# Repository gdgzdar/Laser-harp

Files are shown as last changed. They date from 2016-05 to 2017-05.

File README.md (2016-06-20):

# Laser harp
##Project in progress...

#contact:
- j.cerny.zdar@gmail.com            - organizator
- gdgzdarnadsazavou@gmail.com       - company

##Hardware:
Sensor in frame is 100% completed

Lasers in frame is 100% completed

Arduino LCD display is 1% completed

Ardduino pragraming is 30% completed

##Sofware:
Play sound functions are completed

Play sound async is  completed

Program GUI is 50% completed

Sound Librery now has 8 instruments

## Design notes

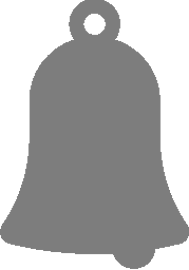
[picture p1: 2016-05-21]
app/images/instruments/iron.png

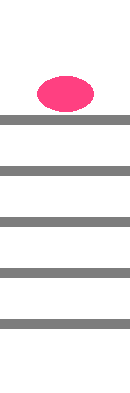
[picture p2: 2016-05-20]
app/images/notes/first-overspace-bass.png

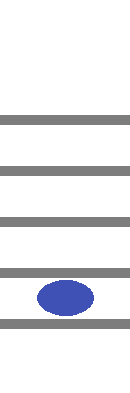
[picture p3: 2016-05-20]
app/images/notes/first-space.png

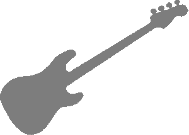
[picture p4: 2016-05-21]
app/images/instruments/bass.png

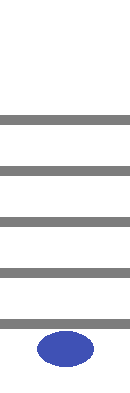
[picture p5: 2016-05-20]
app/images/notes/first-subspace.png

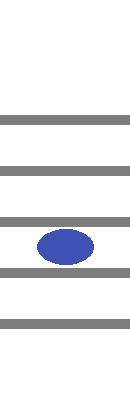
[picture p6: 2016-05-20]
app/images/notes/second-space.png

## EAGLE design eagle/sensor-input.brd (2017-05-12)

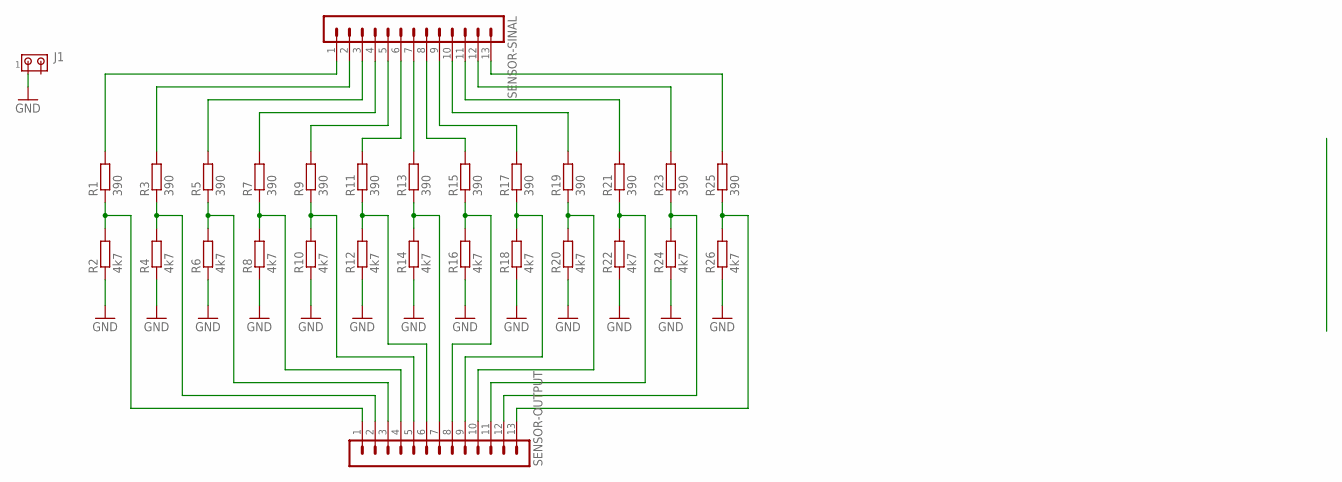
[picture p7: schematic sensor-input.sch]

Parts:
J1: MTA02-100; 10X02MTA
R1, R3, R5, R7, R9, R11, R13, R15, R17, R19, R21, R23, R25: 390; 0207/7
R2, R4, R6, R8, R10, R12, R14, R16, R18, R20, R22, R24, R26: 4k7; 0207/7
SENSOR-OUTPUT: MA13-1
SENSOR-SINAL: MA13-1

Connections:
GND: J1.1, R2.1, R4.1, R6.1, R8.1, R10.1, R12.1, R14.1, R16.1, R18.1, R20.1, R22.1, R24.1, R26.1
unnamed: R3.1, R4.2, SENSOR-OUTPUT.2
unnamed: R1.1, R2.2, SENSOR-OUTPUT.1
unnamed: R5.1, R6.2, SENSOR-OUTPUT.3
unnamed: R7.1, R8.2, SENSOR-OUTPUT.4
unnamed: R9.1, R10.2, SENSOR-OUTPUT.5
unnamed: R11.1, R12.2, SENSOR-OUTPUT.6
unnamed: R13.1, R14.2, SENSOR-OUTPUT.7
unnamed: R15.1, R16.2, SENSOR-OUTPUT.8
unnamed: R17.1, R18.2, SENSOR-OUTPUT.9
unnamed: R19.1, R20.2, SENSOR-OUTPUT.10
unnamed: R21.1, R22.2, SENSOR-OUTPUT.11
unnamed: R23.1, R24.2, SENSOR-OUTPUT.12
unnamed: R25.1, R26.2, SENSOR-OUTPUT.13
unnamed: R1.2, SENSOR-SINAL.1
unnamed: R3.2, SENSOR-SINAL.2
unnamed: R5.2, SENSOR-SINAL.3
unnamed: R7.2, SENSOR-SINAL.4
unnamed: R9.2, SENSOR-SINAL.5
unnamed: R11.2, SENSOR-SINAL.6
unnamed: R13.2, SENSOR-SINAL.7
unnamed: R15.2, SENSOR-SINAL.8
unnamed: R17.2, SENSOR-SINAL.9
unnamed: R19.2, SENSOR-SINAL.10
unnamed: R21.2, SENSOR-SINAL.11
unnamed: R23.2, SENSOR-SINAL.12
unnamed: R25.2, SENSOR-SINAL.13

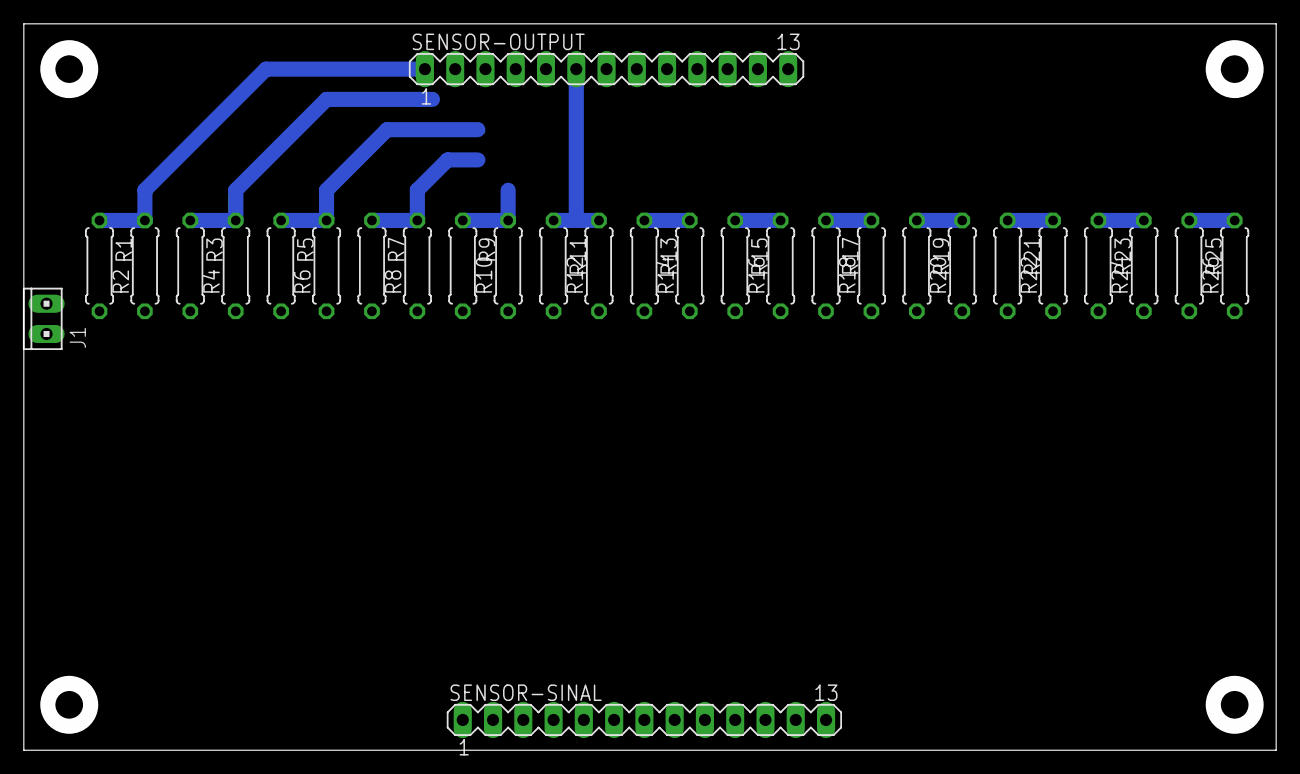
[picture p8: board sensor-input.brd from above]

Board: 2 copper layers, 105.1 x 61.0 mm, 29 parts (0 on the bottom side), 27 nets.

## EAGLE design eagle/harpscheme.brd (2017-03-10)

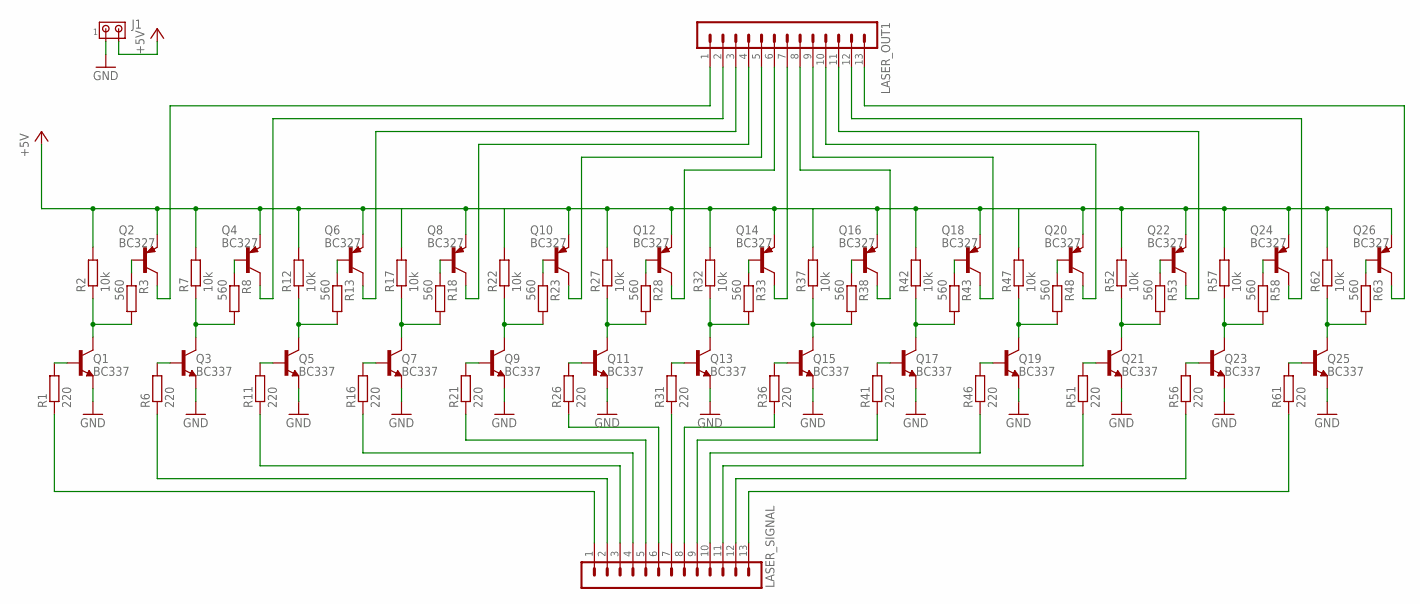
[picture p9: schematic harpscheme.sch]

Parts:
J1: MTA02-100; 10X02MTA
LASER_OUT1: MA13-1
LASER_SIGNAL: MA13-1
Q1, Q3, Q5, Q7, Q9, Q11, Q13, Q15, Q17, Q19, Q21, Q23, Q25: BC337; TO92
Q2, Q4, Q6, Q8, Q10, Q12, Q14, Q16, Q18, Q20, Q22, Q24, Q26: BC327; TO92-EBC
R1, R6, R11, R16, R21, R26, R31, R36, R41, R46, R51, R56, R61: 220; 0207/7
R2, R7, R12, R17, R22, R27, R32, R37, R42, R47, R52, R57, R62: 10k; 0207/7
R3, R8, R13, R18, R23, R28, R33, R38, R43, R48, R53, R58, R63: 560; 0207/7

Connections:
+5V: J1.2, Q2.E, Q4.E, Q6.E, Q8.E, Q10.E, Q12.E, Q14.E, Q16.E, Q18.E, Q20.E, Q22.E, Q24.E, Q26.E, R2.2, R7.2, R12.2, R17.2, R22.2, R27.2, R32.2, R37.2, R42.2, R47.2, R52.2, R57.2, R62.2
GND: J1.1, Q1.1 (E), Q3.1 (E), Q5.1 (E), Q7.1 (E), Q9.1 (E), Q11.1 (E), Q13.1 (E), Q15.1 (E), Q17.1 (E), Q19.1 (E), Q21.1 (E), Q23.1 (E), Q25.1 (E)
unnamed: Q1.2 (B), R1.2
unnamed: Q1.3 (C), R2.1, R3.2
unnamed: Q2.B, R3.1
unnamed: LASER_SIGNAL.7, R31.1
unnamed: LASER_OUT1.1, Q2.C
unnamed: Q3.2 (B), R6.2
unnamed: Q3.3 (C), R7.1, R8.2
unnamed: Q4.B, R8.1
unnamed: LASER_OUT1.2, Q4.C
unnamed: Q5.2 (B), R11.2
unnamed: Q5.3 (C), R12.1, R13.2
unnamed: Q6.B, R13.1
unnamed: LASER_SIGNAL.6, R26.1
unnamed: LASER_OUT1.3, Q6.C
unnamed: Q7.2 (B), R16.2
unnamed: Q7.3 (C), R17.1, R18.2
unnamed: Q8.B, R18.1
unnamed: LASER_SIGNAL.5, R21.1
unnamed: LASER_OUT1.4, Q8.C
unnamed: Q9.2 (B), R21.2
unnamed: Q9.3 (C), R22.1, R23.2
unnamed: Q10.B, R23.1
unnamed: LASER_SIGNAL.4, R16.1
unnamed: LASER_OUT1.5, Q10.C
unnamed: Q11.2 (B), R26.2
unnamed: Q11.3 (C), R27.1, R28.2
unnamed: Q12.B, R28.1
unnamed: LASER_SIGNAL.3, R11.1
unnamed: LASER_OUT1.6, Q12.C
unnamed: Q13.2 (B), R31.2
unnamed: Q13.3 (C), R32.1, R33.2
unnamed: Q14.B, R33.1
unnamed: LASER_SIGNAL.2, R6.1
unnamed: LASER_OUT1.7, Q14.C
unnamed: Q15.2 (B), R36.2
unnamed: Q15.3 (C), R37.1, R38.2
unnamed: Q16.B, R38.1
unnamed: LASER_SIGNAL.1, R1.1
unnamed: LASER_OUT1.8, Q16.C
unnamed: Q17.2 (B), R41.2
unnamed: Q17.3 (C), R42.1, R43.2
unnamed: Q18.B, R43.1
unnamed: LASER_SIGNAL.8, R36.1
unnamed: LASER_OUT1.9, Q18.C
unnamed: Q19.2 (B), R46.2
unnamed: Q19.3 (C), R47.1, R48.2
unnamed: Q20.B, R48.1
unnamed: LASER_SIGNAL.9, R41.1
unnamed: LASER_OUT1.10, Q20.C
unnamed: Q21.2 (B), R51.2
unnamed: Q21.3 (C), R52.1, R53.2
unnamed: Q22.B, R53.1
unnamed: LASER_SIGNAL.10, R46.1
unnamed: LASER_OUT1.11, Q22.C
unnamed: Q23.2 (B), R56.2
unnamed: Q23.3 (C), R57.1, R58.2
unnamed: Q24.B, R58.1
unnamed: LASER_SIGNAL.11, R51.1
unnamed: LASER_OUT1.12, Q24.C
unnamed: Q25.2 (B), R61.2
unnamed: Q25.3 (C), R62.1, R63.2
unnamed: Q26.B, R63.1
unnamed: LASER_SIGNAL.12, R56.1
unnamed: LASER_OUT1.13, Q26.C
unnamed: LASER_SIGNAL.13, R61.1

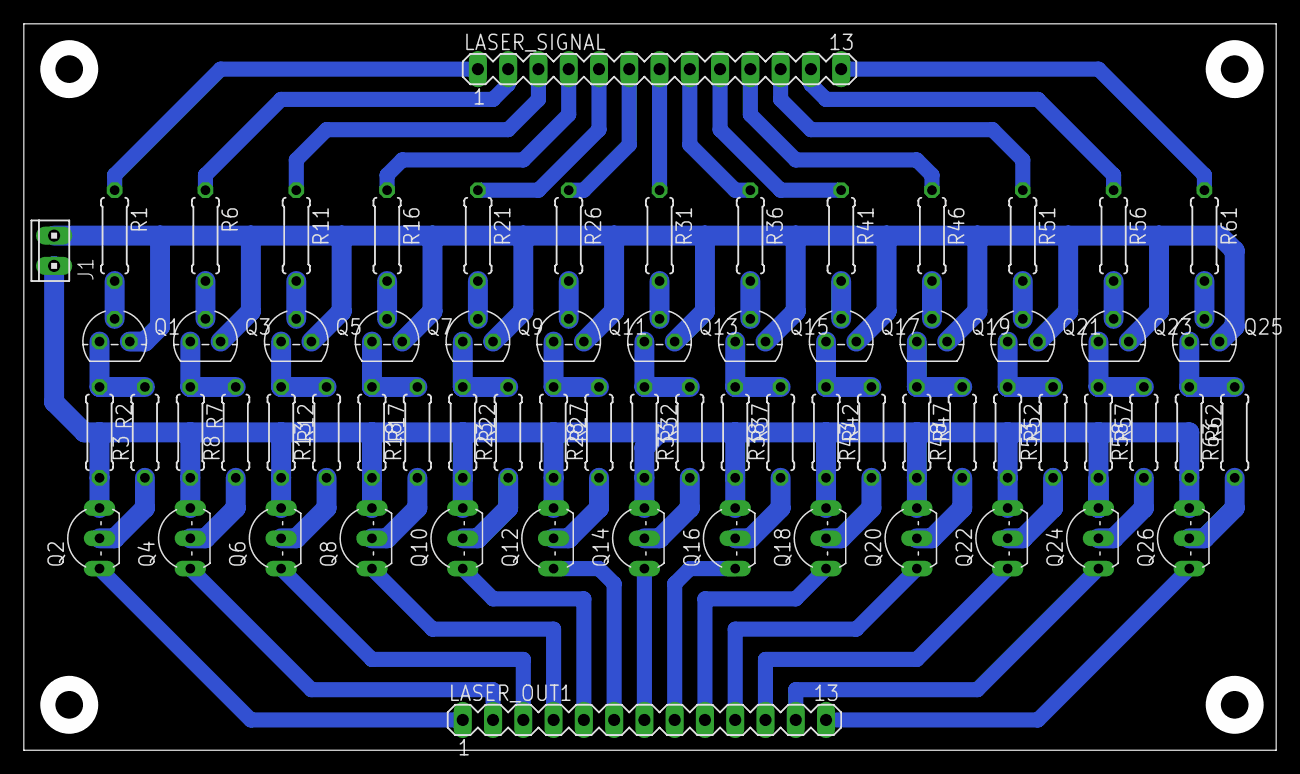
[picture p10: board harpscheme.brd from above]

Board: 2 copper layers, 105.1 x 61.0 mm, 68 parts (0 on the bottom side), 67 nets.

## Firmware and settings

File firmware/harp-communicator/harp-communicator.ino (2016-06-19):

#include "laser.cpp"
#in

static const byte NUMBER_OF_LASERS = 26;
Laser* lasers[NUMBER_OF_LASERS];

void setup() {
  Serial.begin(9600);
  for (int i = 0; i < NUMBER_OF_LASERS; i++) {
    // set pins for lasers and sensors
    int sensorPin = i + 29; // this index may be wrong
    int laserPin = i + 3; // this one too
    Serial.println(laserPin);
    pinMode(laserPin, OUTPUT);    
    pinMode(sensorPin, INPUT);
    digitalWrite(laserPin, HIGH);
    lasers[i] = new Laser(true, false, sensorPin, laserPin);
  }
}

void loop() {
  for(int i = 0; i < NUMBER_OF_LASERS; i++) {
    lasers[i]->isCrossed = digitalRead(lasers[i]->sensorPin) != HIGH;
    Serial.print(lasers[i]->isCrossed);
  }
  Serial.println();
}

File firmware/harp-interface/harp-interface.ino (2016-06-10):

#include "joystick.cpp"

Joystick* joystick;

void setup() {
  joystick = new Joystick(A4, A5, 13);
  Serial.begin(9600);
}

void loop() {
  Serial.print(joystick->getY());
  Serial.print("\n");
  Serial.print(joystick->getX());
  Serial.print("\n");
  Serial.print(joystick->getButtonState());
  Serial.print("\n");
  delay(500);
}

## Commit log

2016-01-28 Add serial print
2016-04-07 Refactor Arduino SW
2016-05-21 refactor directory names for arduino firmware
2016-05-21 add laser harp simulator - virtual harp
2016-05-24 fix compatibility issues with tkinter and openal
    [gui.py]
2016-06-10 refactor and fix joystick read error
    [harp-interface.ino]
2016-06-19 add method for reading from serial port from arduino
2016-06-27 add method to GUI for reading from Arduino
2017-01-20 add thread for player which is listening to arduino and printing what ardiuno sends
2017-01-20 add playing notes from arduino
2017-02-03 add eagle schema & board
    [harpscheme.brd, harpscheme.sch]
2017-02-15 eagle - board draft
    [harpscheme.brd, harpscheme.sch]
2017-04-01 add sensor input schema
    [sensor-input.brd, sensor-input.sch]
